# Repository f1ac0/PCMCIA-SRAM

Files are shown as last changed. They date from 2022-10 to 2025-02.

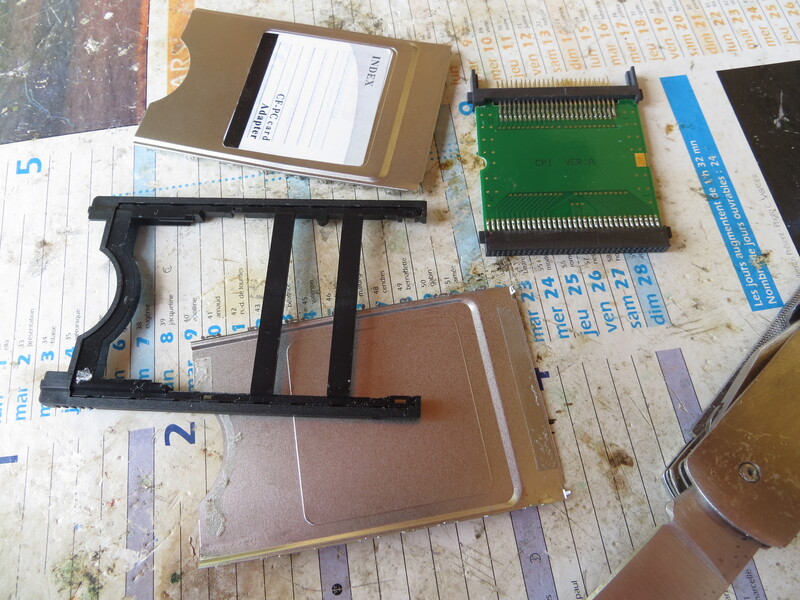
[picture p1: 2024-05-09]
Assembly process/05.The CF-PCMCIA adapter once opened.JPG

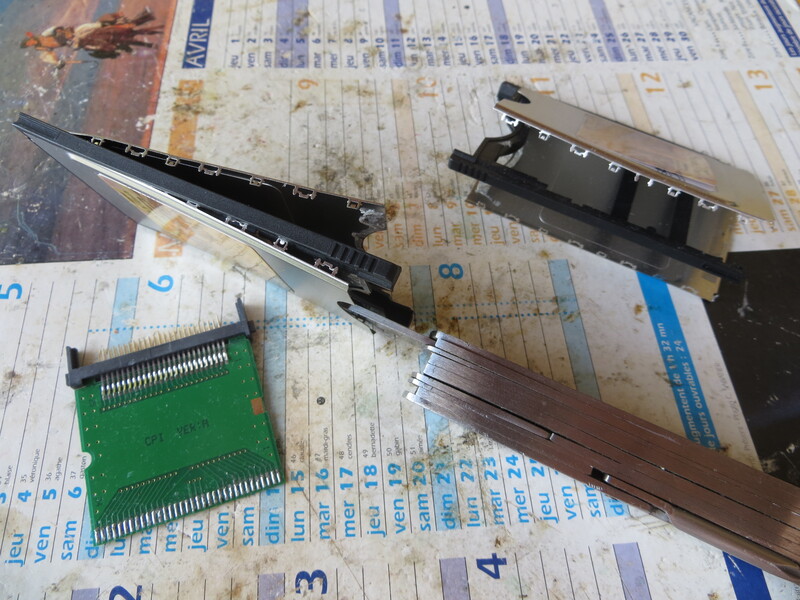
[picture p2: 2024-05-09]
Assembly process/03.Opening the CF-PCMCIA adapter.JPG

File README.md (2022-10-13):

# PCMCIA SRAM
This project is a 4MB or 2MB PCMCIA SRAM for Amiga 600 and 1200, using components available in 2020.

Second hand commercial PCMCIA SRAM cards are rare and expensive. Sakura-IT once created new devices, then published their designs when production was discontinued : https://github.com/Sakura-IT/ppa-pcmcia-sram ; thank you. The idea and CPLD CIS code is inspired from it.

About the project :
- It works in A600 and A1200. It is not tested with any other device. It is 16bit only and does not implement 8bit mode that is required to be compliant to the PCMCIA standard.
- It might work as storage, but is not tested. If you need storage you should just use a CF card and adapter anyway. These days nobody would lose their time fitting a battery in a RAM card.
- It is shorter than a regular PCMCIA card, to be more convenient in our Amiga computers. It is thin enough to fit a standard PCMCIA case. You can fit it in the case and connector of a cheap and available PCMCIA CF adapter. 
- It uses components available in 2020. This is important since there have been several designs but many are already obsolete. Reusing the connector of the aforementioned adapter could be important since they are not so common.
- It uses a 5V SRAM chip to get rid of the level converters. These converters take PCB space, have a cost, and need time to solder. The RAM chip is pricey however, so you might chose to make a 2MB card using just one of it.
- The SRAM chip is fast and the CIS advertise the fastest speed possible. Thanks to this the A600 and A1200 runs faster : they benefit from the added RAM with direct access for the CPU, at least for 16bit applications on the A1200. 

About PCMCIA in Amiga computers, you should already know that its address space is sometimes used by internal accelerators and cannot be used at the same time. If you have such an accelerator, you might not be interested to use this project in the same computer anyway. 

# Disclaimer
This is a hobbyist project, it comes with no warranty and no support. Also remember that the Amiga machines are about 30 years old and may fail because of such hardware expansions.

I publish my work under the CC-BY-NC-SA license. The content of this repository is the result of weeks of work, requiring investment in tools, parts, prototypes, and risky tests on his own equipment. For this reason the author does not want third parties to sell products and keep all the profit, usually without even offering support to their customers. If you see people selling this without the consent of the author, don't buy from them.

If you find it useful and want to reward me : I am always looking for Amiga/Amstrad CPC hardware to repair and hack, please contact me.

# BOM
- 1x or 2x CY62167ELL-45ZXI 5V SRAM (do not use 3.3V CY6167EV !) or 1x CY62177ESL--55ZXI 5V SRAM (not tested by me, tell me if this works for you)
- 1x XC9536XL CPLD
- 1x SPX3819M5-L-3-3 3.3v LDO
- 2x 1uF (or more) 0805 capacitors
- 4x or 5x 100nF 0805 capacitors
- 1x female 68pin PCMCIA connector, or a PCMCIA CF adapter from which you will reuse the connector and case

# Making it
I recommend 0.6mm or 0.8mm PCB since it needs to accommodate the PCMCIA connector and height.

Components are SMD, and TSOP RAM have thin pin pitch. You need to know what you are doing.

Check for shorts at least between 5V, 3.3V, and GND traces before applying power !

The programming port does not need to be soldered since it needs to be programmed just once : you can just hold it in place during the few seconds required for programming.

CPLD code is generated using Xilinx ISE 14.7. There are several methods to program the XC9536XL. I personally use xsvfduino : https://github.com/wschutzer/xsvfduino

NOTE : There are solder pads on the PCB that could be used to implement 8/16bit mode and the "high byte on low pins" feature. Cypress replied that the BYTE mode cannot be used dynamically so it might not work. Amiga computers do not and can not use it anyway.

# Case
To reuse a PCMCIA CF adapter case and connector you first need to disassemble the two metal parts from the plastic body.
- The metal parts are identical and held together by hooks every cm on their long sides. Place the adapter vertically with the long side on the bench. Insert a knife blade between the plastic and the metal on the side of the CF opening, cut the glue, and push down to remove the first hook. The hooks on each side are alternated, so after opening the first one on the left you need to open the next from the right, and so on. Do the same on the other log side. The two remaining hooks are on the short side besides the PCMCIA connector, and the metal part is glued to the PCMCIA connector.
- To desolder the connector from the PCB : lift each pin carefully. Use flux.
- Before soldering the PCMCIA connector to your PCB, bend the pins back to their original place so they will make contact to the PCB. Make sure the board and connector are correctly lined up.
- Cut the indent in the plastic body so you can place the board with soldered connector inside. Cut the plastic body 1 or 2 mm longer than the PCB end.
- Ensure that the PCB is installed the correct way in the plastic body : the guides on the plastic body are keyed. The component side is the top side. THIS IS VERY IMPORTANT.
- Test your card before closing the case. Use AmigaTestKit (https://github.com/keirf/Amiga-Stuff/tree/master/testkit) to test the full 4Mb. Once you are sure the board is OK then you are ready to enclose it.
- With strong scissors, cut both metal parts about 1mm shorter than the plastic body. You may damage your scissors however the result is far better than using a saw.
- Be sure that the metal parts are in good shape and the hooks are aligned. Place the lower one in the plastic body.
- Insulate the top one with tape, at least where the capacitors may touch it. Then place it in the plastic body : the hooks will close it.
- The rear end with sharp metal edges require a protection for your fingers. I personally seal it with hot glue.

# Using it
- Plug it to the PCMCIA port
- Turn amiga on

If you care about your Amiga, this might be a bad idea to plug or unplug the device while live. However if you want to access the CIS info using PrepCard, you need to plug the card after powering the computer.

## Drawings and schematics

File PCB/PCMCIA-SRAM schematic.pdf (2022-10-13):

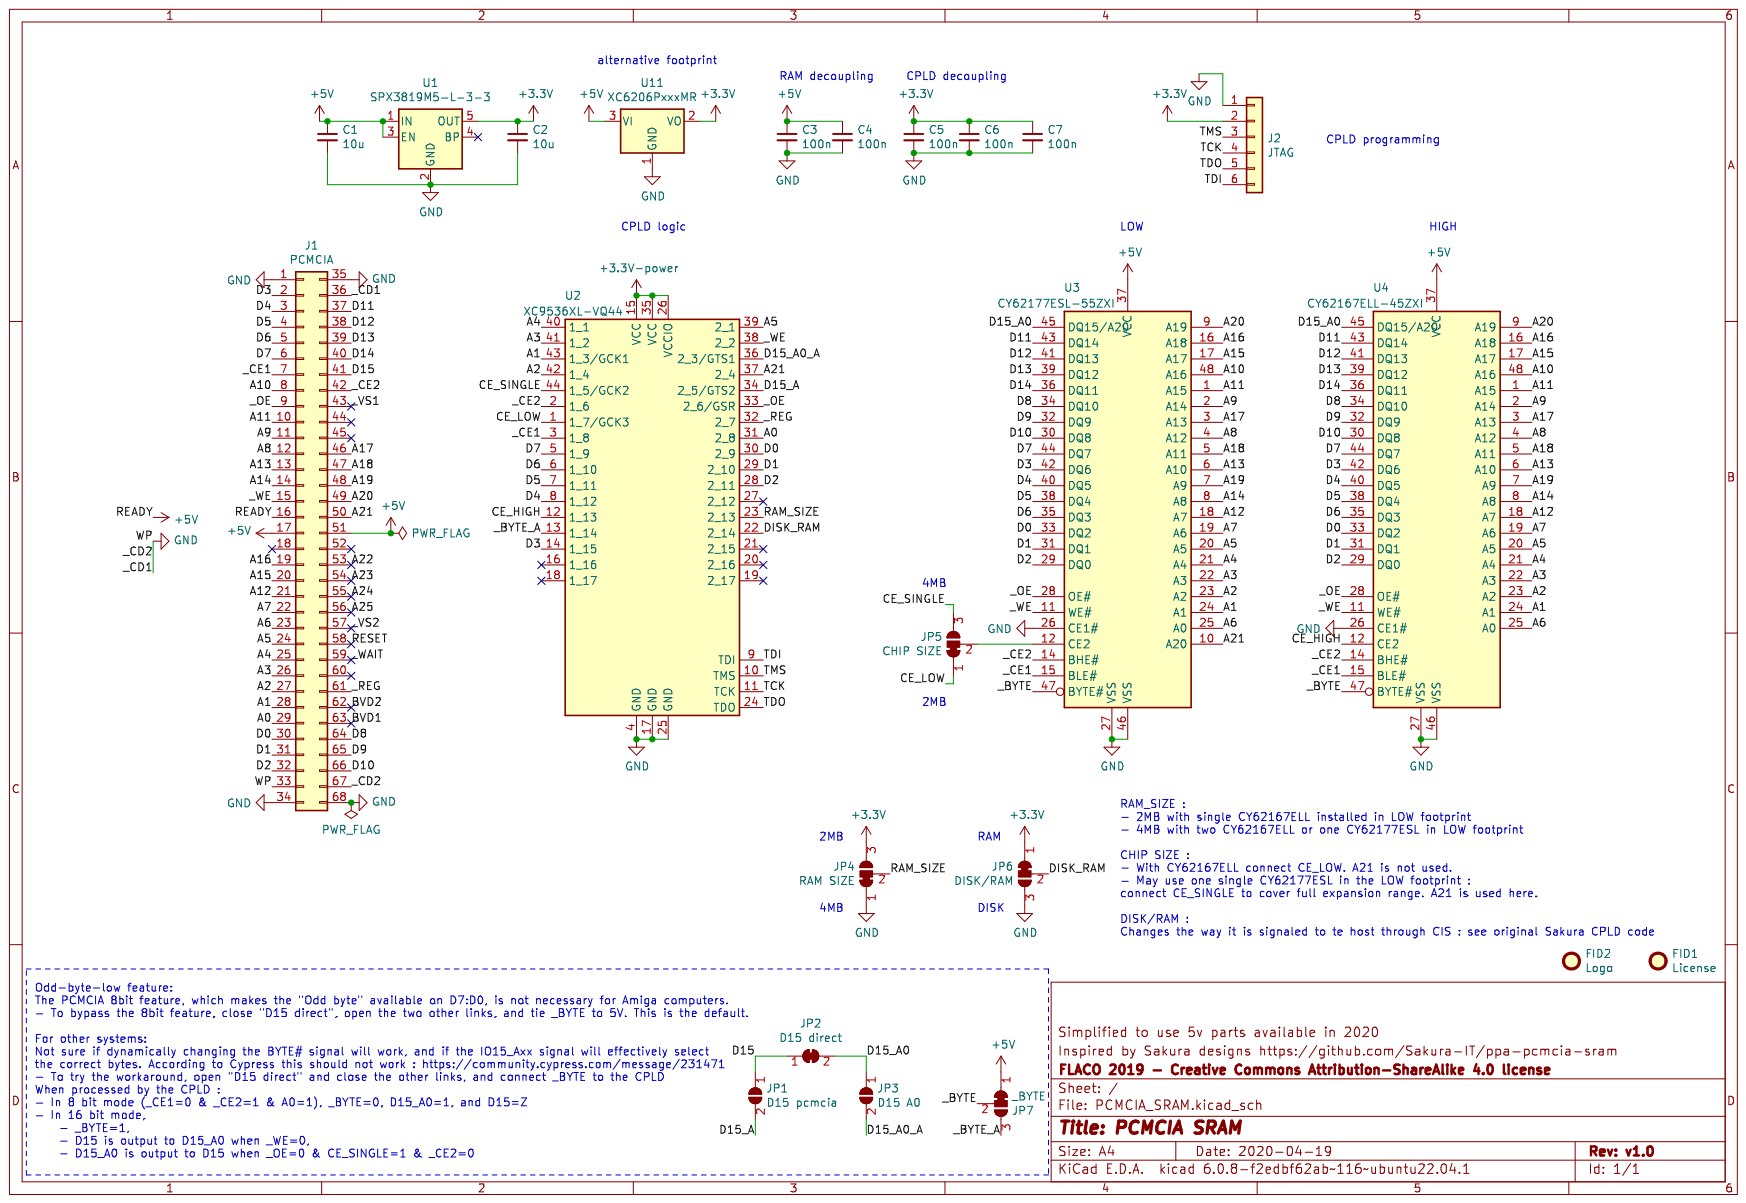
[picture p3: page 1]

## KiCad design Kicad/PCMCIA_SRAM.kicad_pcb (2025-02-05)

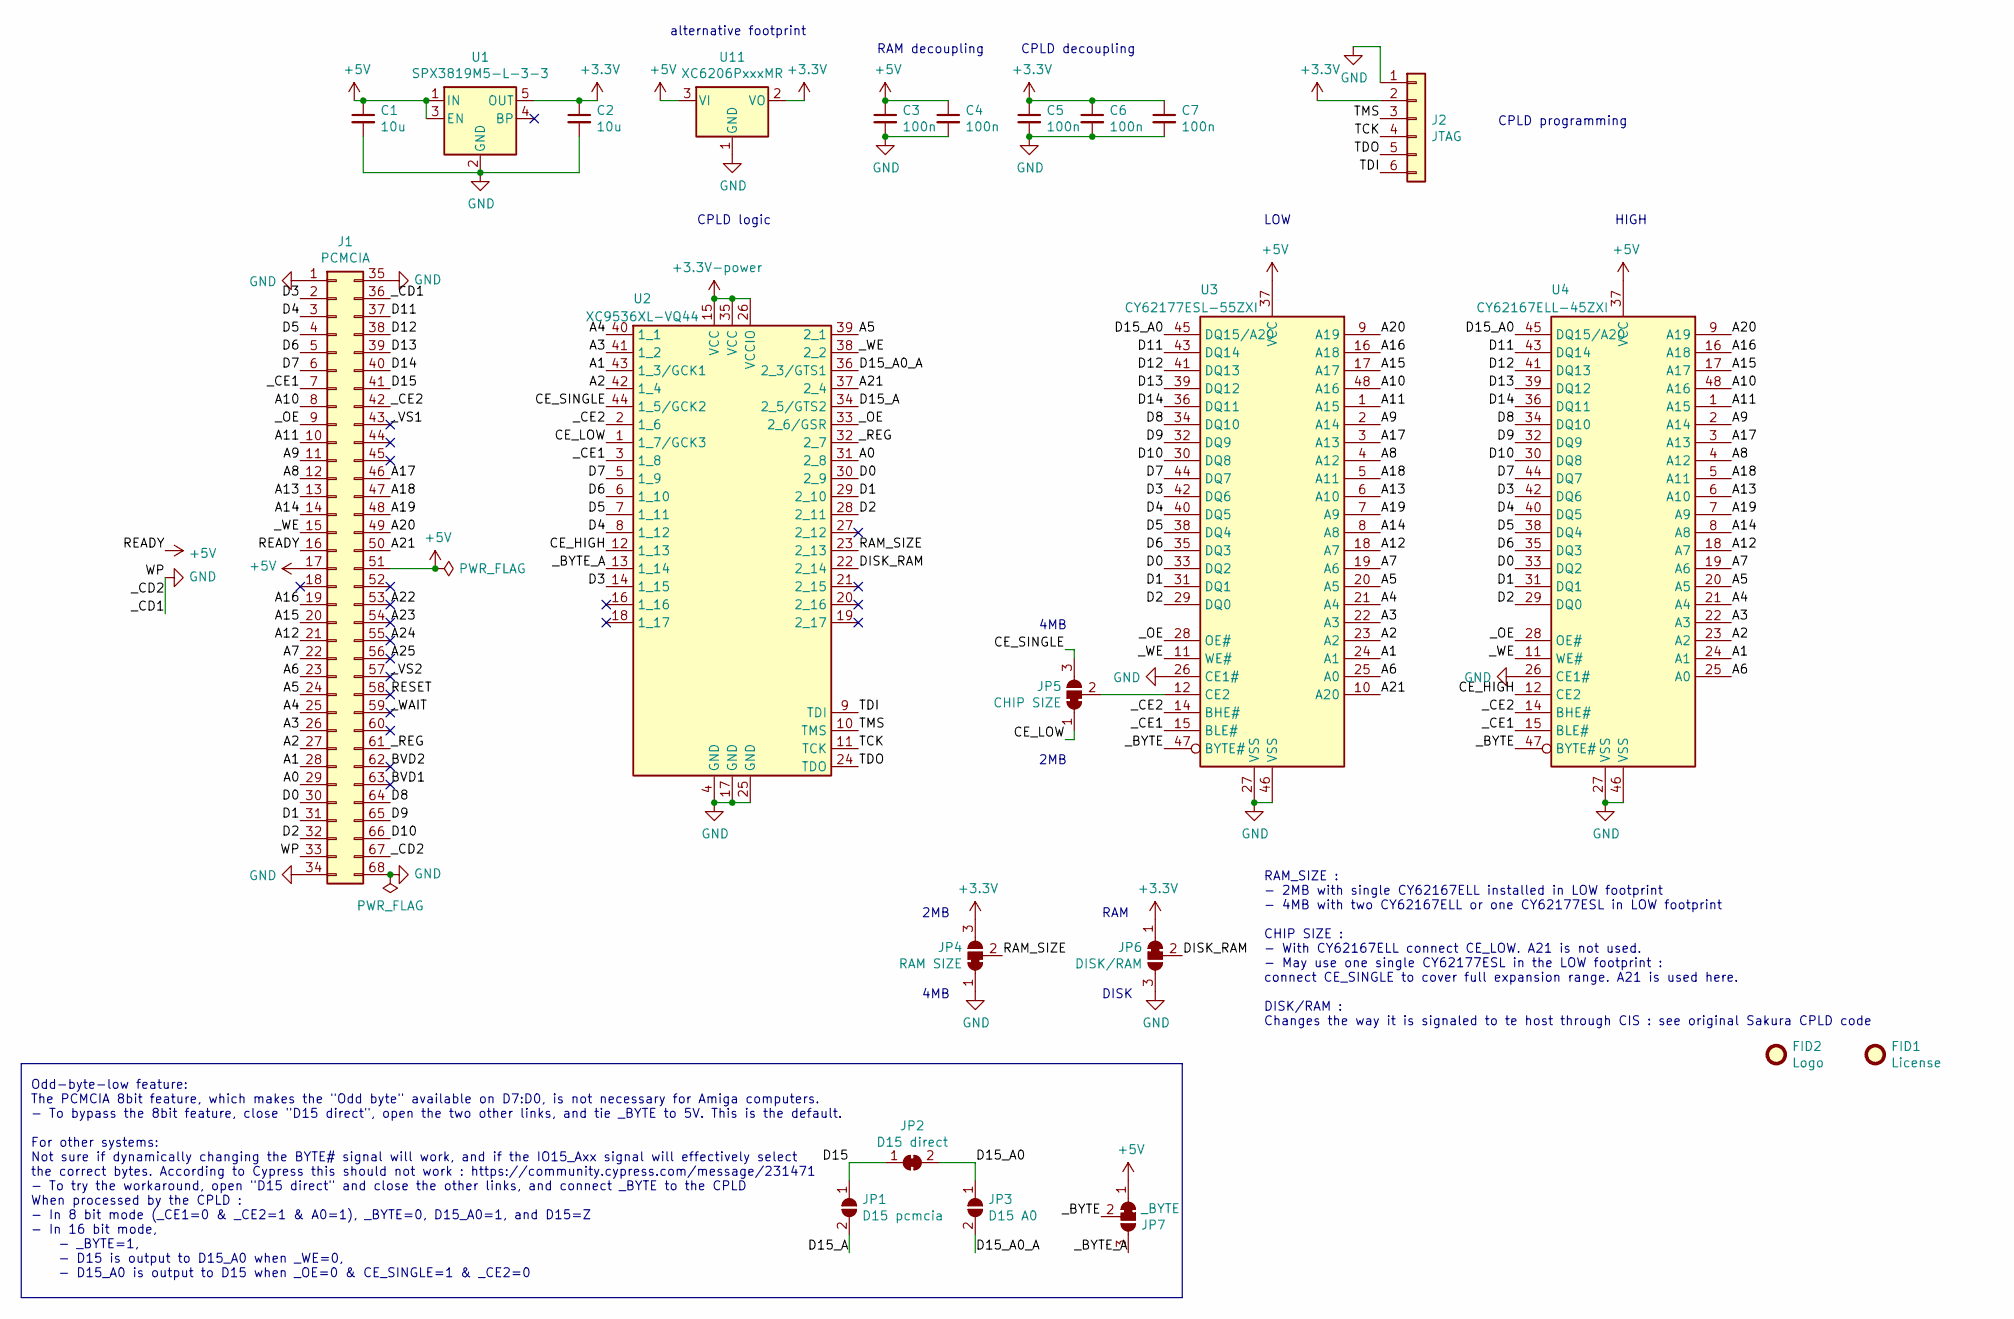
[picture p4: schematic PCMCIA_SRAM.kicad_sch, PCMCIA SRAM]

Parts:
C1, C2: 10u; C_0805_2012Metric
C3, C4, C5, C6, C7: 100n; C_0805_2012Metric
FID1: License; CC_BY_NC_SA_square_silkscreen
FID2: Logo; PIC_Cassepanards_GS
J1: PCMCIA; PCMCIA_female_edge_connector
J2: JTAG; PinHeader_1x06_P2.54mm_Vertical
JP1: D15 pcmcia; SolderJumper-2_P1.3mm_Open_RoundedPad1.0x1.5mm
JP2: D15 direct; SolderJumper-2_P1.3mm_Bridged_RoundedPad1.0x1.5mm
JP3: D15 A0; SolderJumper-2_P1.3mm_Open_RoundedPad1.0x1.5mm
JP4: RAM SIZE; SolderJumper-3_P1.3mm_Bridged12_RoundedPad1.0x1.5mm
JP5: CHIP SIZE; SolderJumper-3_P1.3mm_Bridged12_RoundedPad1.0x1.5mm
JP6: DISK/RAM; SolderJumper-3_P1.3mm_Bridged12_RoundedPad1.0x1.5mm
JP7: _BYTE; SolderJumper-3_P1.3mm_Bridged12_RoundedPad1.0x1.5mm
U1: SPX3819M5-L-3-3; SOT-23-5
U2: XC9536XL-VQ44; LQFP-44_10x10mm_P0.8mm
U3: CY62177ESL-55ZXI; TSOP-I-48_18.4x12mm_P0.5mm
U4: CY62167ELL-45ZXI; TSOP-I-48_18.4x12mm_P0.5mm
U11: XC6206PxxxMR; SOT-23

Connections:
+5V: C1.1, C3.1, C4.1, J1.16, J1.17, J1.51, JP7.1 (A), U1.1 (IN), U1.3 (EN), U3.37 (VCC), U4.37 (VCC), U11.3 (VI)
/A0: J1.29, U2.31 (2_8)
/A1: J1.28, U2.43 (1_3/GCK1), U3.24 (A1), U4.24 (A1)
/A2: J1.27, U2.42 (1_4), U3.23 (A2), U4.23 (A2)
/A3: J1.26, U2.41 (1_2), U3.22 (A3), U4.22 (A3)
/A4: J1.25, U2.40 (1_1), U3.21 (A4), U4.21 (A4)
/A5: J1.24, U2.39 (2_1), U3.20 (A5), U4.20 (A5)
/A6: J1.23, U3.25 (A0), U4.25 (A0)
/A7: J1.22, U3.19 (A6), U4.19 (A6)
/A8: J1.12, U3.4 (A12), U4.4 (A12)
/A9: J1.11, U3.2 (A14), U4.2 (A14)
/A10: J1.8, U3.48 (A16), U4.48 (A16)
/A11: J1.10, U3.1 (A15), U4.1 (A15)
/A12: J1.21, U3.18 (A7), U4.18 (A7)
/A13: J1.13, U3.6 (A10), U4.6 (A10)
/A14: J1.14, U3.8 (A8), U4.8 (A8)
/A15: J1.20, U3.17 (A17), U4.17 (A17)
/A16: J1.19, U3.16 (A18), U4.16 (A18)
/A17: J1.46, U3.3 (A13), U4.3 (A13)
/A18: J1.47, U3.5 (A11), U4.5 (A11)
/A19: J1.48, U3.7 (A9), U4.7 (A9)
/A20: J1.49, U3.9 (A19), U4.9 (A19)
/A21: J1.50, U2.37 (2_4), U3.10 (A20)
/A22: J1.53
/A23: J1.54
/A24: J1.55
/A25: J1.56
/BVD1: J1.63
/BVD2: J1.62
/CE_HIGH: U2.12 (1_13), U4.12 (CE2)
/CE_LOW: JP5.1 (A), U2.1 (1_7/GCK3)
/CE_SINGLE: JP5.3 (B), U2.44 (1_5/GCK2)
/D0: J1.30, U2.30 (2_9), U3.33 (DQ2), U4.33 (DQ2)
/D1: J1.31, U2.29 (2_10), U3.31 (DQ1), U4.31 (DQ1)
/D2: J1.32, U2.28 (2_11), U3.29 (DQ0), U4.29 (DQ0)
/D3: J1.2, U2.14 (1_15), U3.42 (DQ6), U4.42 (DQ6)
/D4: J1.3, U2.8 (1_12), U3.40 (DQ5), U4.40 (DQ5)
/D5: J1.4, U2.7 (1_11), U3.38 (DQ4), U4.38 (DQ4)
/D6: J1.5, U2.6 (1_10), U3.35 (DQ3), U4.35 (DQ3)
/D7: J1.6, U2.5 (1_9), U3.44 (DQ7), U4.44 (DQ7)
/D8: J1.64, U3.34 (DQ10), U4.34 (DQ10)
/D9: J1.65, U3.32 (DQ9), U4.32 (DQ9)
/D10: J1.66, U3.30 (DQ8), U4.30 (DQ8)
/D11: J1.37, U3.43 (DQ14), U4.43 (DQ14)
/D12: J1.38, U3.41 (DQ13), U4.41 (DQ13)
/D13: J1.39, U3.39 (DQ12), U4.39 (DQ12)
/D14: J1.40, U3.36 (DQ11), U4.36 (DQ11)
/D15: J1.41, JP1.1 (A), JP2.1 (A)
/D15_A: JP1.2 (B), U2.34 (2_5/GTS2)
/D15_A0: JP2.2 (B), JP3.1 (A), U3.45 (DQ15/A20), U4.45 (DQ15/A20)
/D15_A0_A: JP3.2 (B), U2.36 (2_3/GTS1)
/DISK_RAM: JP6.2 (C), U2.22 (2_14)
/RAM_SIZE: JP4.2 (C), U2.23 (2_13)
/RESET: J1.58
/TCK: J2.4, U2.11 (TCK)
/TDI: J2.6, U2.9 (TDI)
/TDO: J2.5, U2.24 (TDO)
/TMS: J2.3, U2.10 (TMS)
/_BYTE: JP7.2 (C), U3.47 (BYTE#), U4.47 (BYTE#)
/_BYTE_A: JP7.3 (B), U2.13 (1_14)
/_CE1: J1.7, U2.3 (1_8), U3.15 (BLE#), U4.15 (BLE#)
/_CE2: J1.42, U2.2 (1_6), U3.14 (BHE#), U4.14 (BHE#)
/_OE: J1.9, U2.33 (2_6/GSR), U3.28 (OE#), U4.28 (OE#)
/_REG: J1.61, U2.32 (2_7)
/_VS1: J1.43
/_VS2: J1.57
/_WAIT: J1.59
/_WE: J1.15, U2.38 (2_2), U3.11 (WE#), U4.11 (WE#)
GND: C1.2, C2.2, C3.2, C4.2, C5.2, C6.2, C7.2, J1.1, J1.33, J1.34, J1.35, J1.36, J1.67, J1.68, J2.1, JP4.1 (A), JP6.3 (B), U1.2 (GND), U2.4 (GND), U2.17 (GND), U2.25 (GND), U3.26 (CE1#), U3.27 (VSS), U3.46 (VSS), U4.26 (CE1#), U4.27 (VSS), U4.46 (VSS), U11.1 (GND)
unnamed: JP5.2 (C), U3.12 (CE2)

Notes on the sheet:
2MB
4MB
DISK
RAM
HIGH
alternative footprint
CPLD programming
CPLD decoupling
LOW
RAM decoupling
Odd-byte-low feature: The PCMCIA 8bit feature, which makes the "Odd byte" available on D7:D0, is not necessary for Amiga computers. - To bypass the 8bit feature, close "D15 direct", open the two other links, and tie _BYTE to 5V. This is the default. For other systems: Not sure if dynamically changi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
CPLD logic
RAM_SIZE : - 2MB with single CY62167ELL installed in LOW footprint - 4MB with two CY62167ELL or one CY62177ESL in LOW footprint CHIP SIZE : - With CY62167ELL connect CE_LOW. A21 is not used. - May use one single CY62177ESL in the LOW footprint : connect CE_SINGLE to cover full expansion range. A21 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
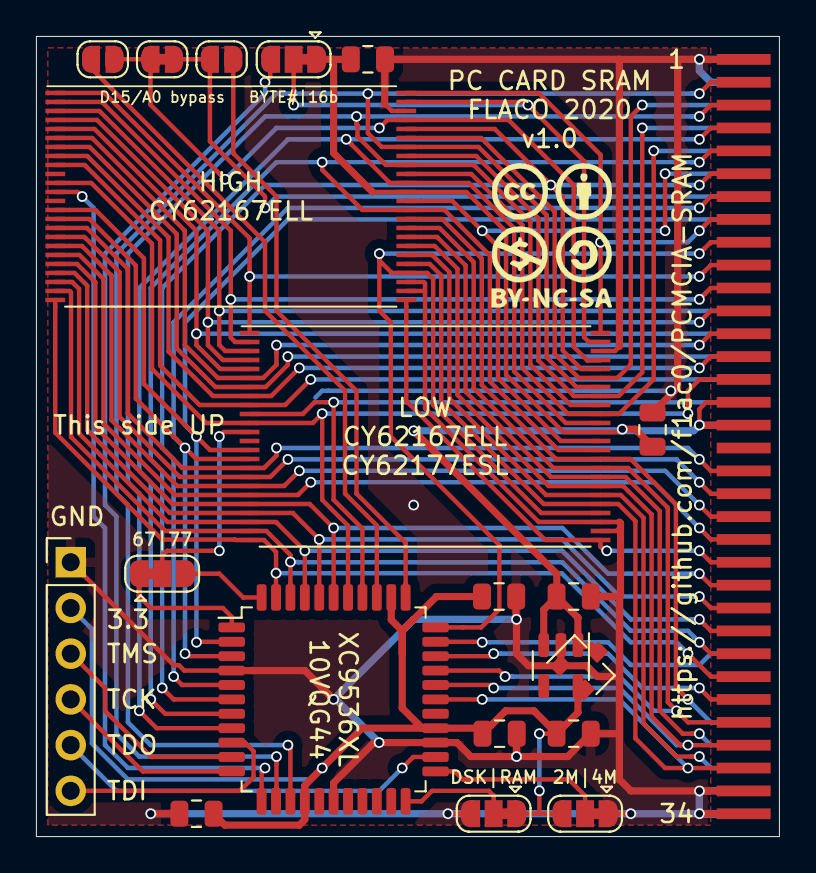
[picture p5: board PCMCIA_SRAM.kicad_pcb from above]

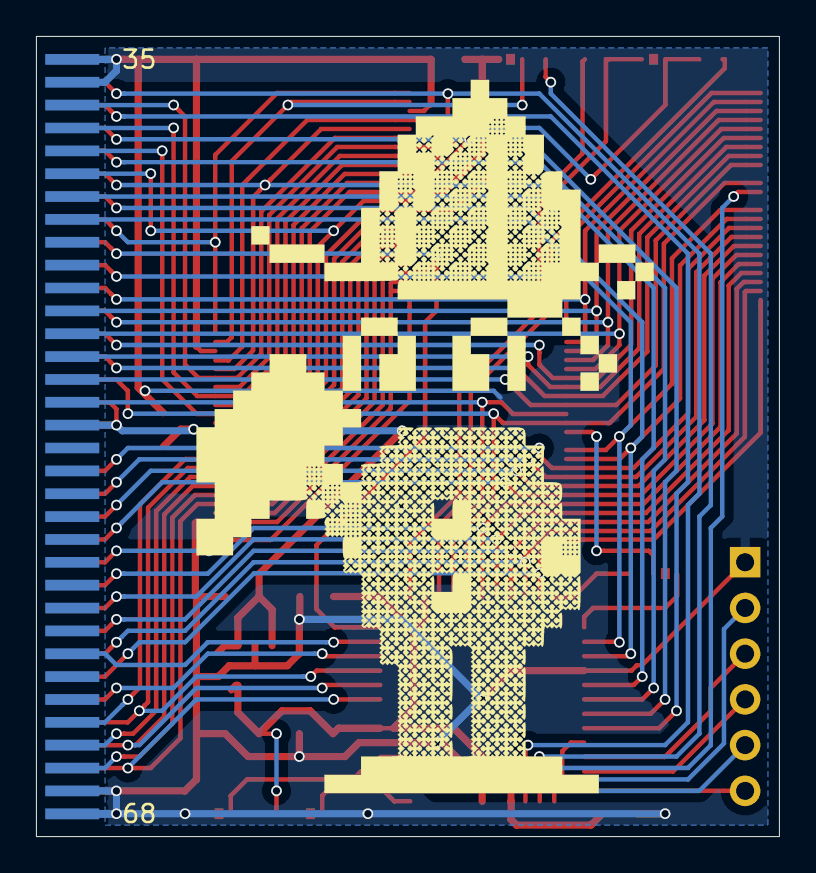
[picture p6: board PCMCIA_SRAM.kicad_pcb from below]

Board: 2 copper layers, 41.3 x 44.5 mm, 23 parts (2 on the bottom side), 61 nets.

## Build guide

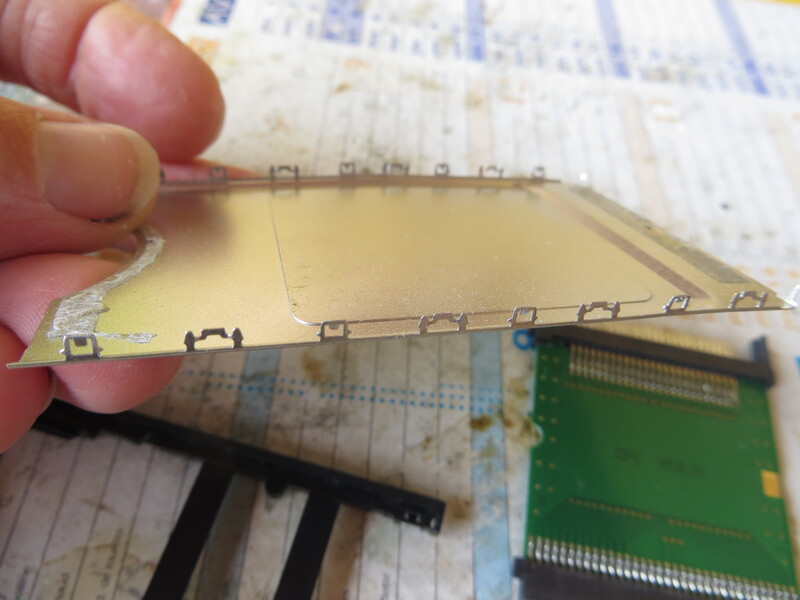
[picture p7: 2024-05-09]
Assembly process/04.The metallic clipses you need to open.JPG

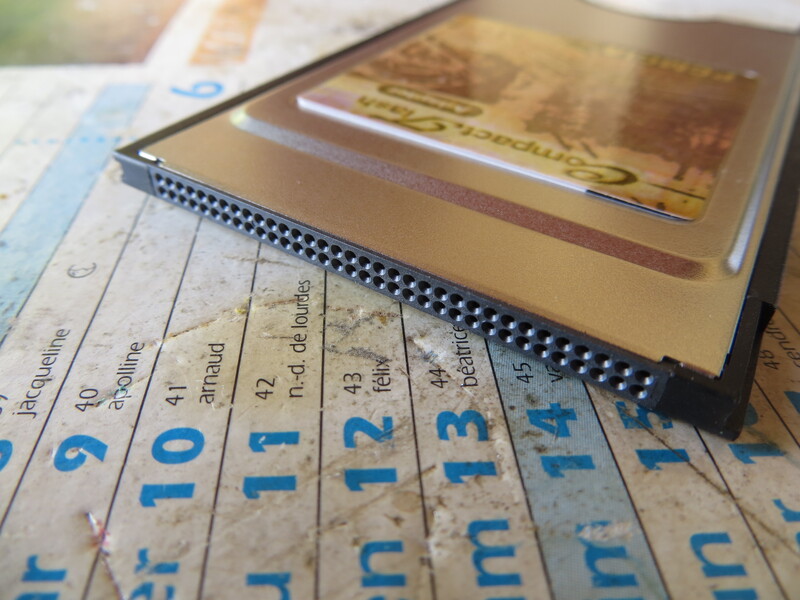
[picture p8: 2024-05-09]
Assembly process/02.The CF-PCMCIA connector.JPG

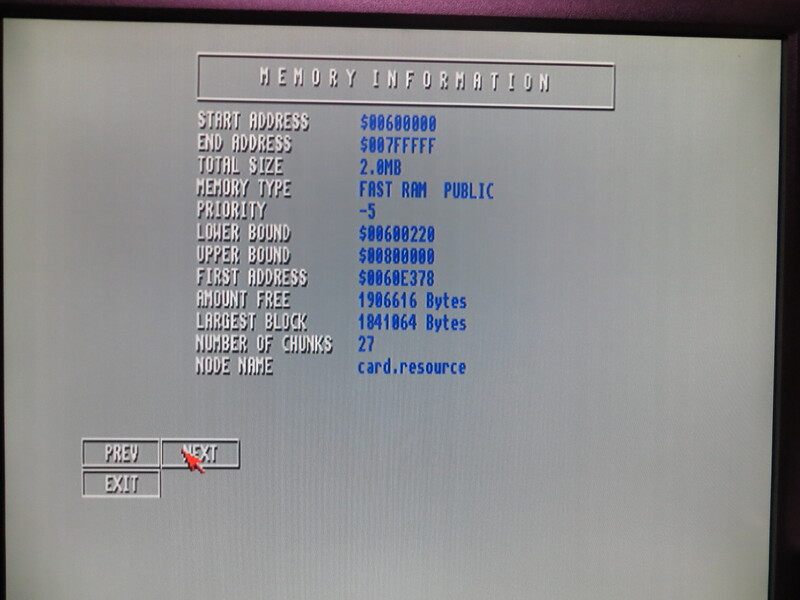
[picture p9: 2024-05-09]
Assembly process/11.The board is detected by SysInfo.JPG

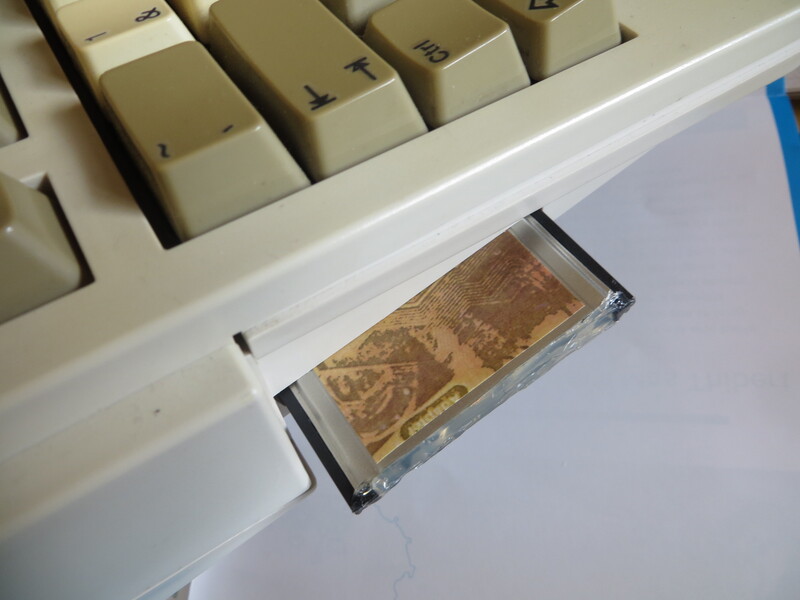
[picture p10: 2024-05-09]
Assembly process/19.Ready to go.JPG

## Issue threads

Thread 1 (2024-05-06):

CY62167ELL-45ZXI

hardgb, 2024-05-06:
First I apologize for my English, it is terrible.
I also want to thank you for the project. I am very interested in assembling at least 2 units of this PCMCIA SRAM for my 2 A600.
I have a doubt.
#The "CY62167ELL-45ZXI" that I'm finding is 3.6V, I can't find the 5V one. Can I use it?

Do you have a video showing how this card works?
Do you have more photos of the card?

My email: hard_gb@hotmail.com

f1ac0, 2024-05-09:
Hello hargb,
As stated in the readme, it is important to use 5V parts, since there is no voltage conversion on the board that would make it far more complicated and larger.
There are other Cypress SRAM chips that run at lower voltages. The CY62167ELL-45ZXI also internally runs at at a lower voltage but has an internal regulator and 5V tolerant pins, maybe this is the reason why yous vendor states it is 3.6V in his description ?

I just added the photos I have inside the repo to help for the assembly process.

I suggest you remove your email from your comment, spammers will target you.

hardgb, 2024-05-09:
Many thanks for the reply.
I tried to do it

f1ac0, 2024-05-09:
Here are some additional advice for the assembly :
- The board has two overlapping footprints for two possible regulators. I see that I forgot to mention in the readme that the SOT23 one I used is a XC6206P332MR. Look at the ibom file how to install it
- On picture n°9 the board has only one CY62167ELL-45ZXI RAM chip : this was during development, that would need a different CPLD logic, so you need to install both.
- If you do not have a Xilinx programmer, look at https://github.com/f1ac0/xsvfduino. You may also use a raspberry Pi, see https://github.com/f1ac0/PistormX/tree/main/Alpha#programming-the-cpld-from-the-pi
- Look at the photo how the metallic clipses are made, to remove them it is easier to start on the CF side, insert the knife in order to always push out the base of the small clips that has a small "tongue" that grips to the longer clips from the other lid.
- When desoldering the PCMCIA connector, be careful not to bend too much the pins since they are fragile. You need to use a lot of flux and a desoldering braid in order to remove as much solder as possible to help in the process
- Always check for shorts, at least on the power rails, before powering it to program the CPLD and connecting it to your system
- Test it before you put it inside the enclosure
- Beware of the sharp edges of the metallic covers
Good luck !

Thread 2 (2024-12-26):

Npn-attribute memory option for old scope

Kobbe1, 2024-12-26:
Hi @f1ac0 ,
I was thinking to maybe build one of these PCBs to resurrect one of my LeCroy scopes - which will require some changes to the source code it seems, some details of what is required are here:
https://github.com/Sakura-IT/ppa-pcmcia-sram/issues/1

Also here just FYI regarding the background:
https://groups.io/g/LeCroyOwnersGroup/topic/lt342_boot_issue/77501370

I should be able to build the PCB, I have access to a microscope etc. if needed, and I think I can figure the FPGA programming - but how do I adjust the source code? Primarily regarding the above "non-attribute" adjustments as well as adjusting for only the one used SRAM chip so I get a 2Mb card ...
Or is zhis using the original source code from https://github.com/Sakura-IT/ppa-pcmcia-sram/tree/master/cpld/src ?

Thanks,

-T

f1ac0, 2024-12-27:
Hi Kobbe1,
I just added a new file that does not respond to ROM attributes, the same as what you pointed inside the Sakura-IT repo.
Without the ROM attribute, there is nothing to do in the firmware to have a 2MB card: just install the LOW ram chip and leave the HIGH one unpopulated.
Please report if you have the opportunity to try it.

Kobbe1, 2024-12-27:
I am about to order the PCB and components from Ali, and realized that of course the design has no battery, so obviously it will lose whatever I write to it when I pull this from the PCMCIA slot.

Obviously that is not an issue when being used in an Amiga (I had an A600 and A1200 once back in the day :) btw ) - but here for the scope I guess I will need to attach a battery to externally power it after programming.

The background is that my LeCroy scope LT344 has lost its firmware, so I need to write the firmware to a "linear non-attribute SRAM" card and then boot the scope from there, then flash it back to the original IC.

It wont be an issue really, I can put some USB connector on the back and power it from an power bank for example, just wanted to hear your thoughts ...

f1ac0, 2024-12-28:
The PCB is not designed to use a battery to power the RAM chips : no terminals for it, no protection to prevent sending power from the battery to the host system when it is off or feeding the 5V from the host inside the battery. In addition the RAM chips use an active high CE pin that could prevent selecting the chip and writing to it when the CPLD is not powered, but the PCB is not designed to power only the RAM chips and shut down the LDO and the CPLD.

You may lift the PCMCIA pins 16,17 and 51 and install a 3.3V-5V battery terminals around C1, C3 or C4 and see if it is enough for your application.
If not, then you would have to solder all the PCMCIA pins then cut the 5V trace just in front of pin 37 of U3 the LOW ram chip (to isolate it from the LDO/CPLD and host system) then connect the battery around C4 to power the RAM chip.

See the IBOM file to locate the chips.

A you say this was designed to be used with Amiga computers and it does not implement switching between 8bits and 16bits modes that are part of the PCMCIA spec. I do not know if there are systems using this feature.

Kobbe1, 2025-08-15:
Hi,
I found some time and energy to finally try to program the device.
Unfortunately I did not get it to respond.

I am using a serial to USB device.

I start the upload through python, and get the "ready to send". Then press reset on the bluepill.

Of course it might be the soldering, but I have no way to really debug this. The PCB looks a bit nasty but that is mostly dust as it was sitting here for months on my desk ...

I did try it earlier with the USBserial of the bluepill, there was more output but also no actual programming. Will try again ...

`
C:\Users\Kobbe>python "D:\Dev\send_xsvf" -p COM8 "D:\Dev\PCMCIA_RAM_no_attribute_ROM.xsvf"
Ready to send file of size 39453 bytes.

<pressed reset here>

DEBUG:  A
Device is ready.
DEBUG: SENT:  07201200120104000000000208fe0800000020010fffffff0900000000f96020
DEBUG:  G    sizeof( SXsvfInfo ) = 1848 bytes

Device: sizeof( SXsvfInfo ) = 1848 bytes
DEBUG:  G   TMS Reset Sequence -> Test-Logic-Reset
Device: TMS Reset Sequence -> Test-Logic-Reset
DEBUG:  G   TAP State = RESET
Device: TAP State = RESET
`

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

Kobbe1, 2025-08-15:
bit more progress by flashing the right bootloader to use the USBSerial. Probably this comes down to hw problem now, might need to resolder or replace FPGA ...

```
C:\Users\Kobbe>python "D:\Dev\send_xsvf" -p COM9 "D:\Dev\PCMCIA_RAM_no_attribute_ROM.xsvf"
Ready to send file of size 39453 bytes.
DEBUG:  A
Device is ready.
DEBUG: SENT:  07201200120104000000000208fe0800000020010fffffff0900000000f96020
DEBUG:  G  XREPEAT

Device: XREPEAT
DEBUG:  G   XREPEAT = 32
Device: XREPEAT = 32
DEBUG:  G  XSTATE
Device: XSTATE
DEBUG:  G   TMS Reset Sequence -> Test-Logic-Reset
Device: TMS Reset Sequence -> Test-Logic-Reset
DEBUG:  G   TAP State = RESET
Device: TAP State = RESET
DEBUG:  G  XSTATE
Device: XSTATE
DEBUG:  G   TAP State = RUNTEST/IDLE
Device: TAP State = RUNTEST/IDLE
DEBUG:  G  XRUNTEST
Device: XRUNTEST
DEBUG:  G   XRUNTEST = 0
Device: XRUNTEST = 0
DEBUG:  G  XSIR
Device: XSIR
DEBUG:  G   XSIR length = 8
Device: XSIR length = 8
DEBUG:  G   Shift Length = 8
Device: Shift Length = 8
DEBUG:  G    TDI          = 0xfe
Device: TDI          = 0xfe
DEBUG:  G    TDO Expected =
Device: TDO Expected =
DEBUG:  ff
Unrecognized line: ff
DEBUG:  G  XSDRTDO
Device: XSDRTDO
DEBUG:  A
DEBUG: SENT:  930208ff0208e8080000000601000905000208ed0400030d4008000000120100
DEBUG:  G   Shift Length = 32

Device: Shift Length = 32
DEBUG:  G    TDI          = 0x00000000
Device: TDI          = 0x00000000
DEBUG:  G    TDO Expected = 0xf9602093
Device: TDO Expected = 0xf9602093
DEBUG:  G   TAP State = DRSELECT
Device: TAP State = DRSELECT
DEBUG:  G   TAP State = DRCAPTURE
Device: TAP State = DRCAPTURE
DEBUG:  G   TAP State = DRSHIFT
Device: TAP State = DRSHIFT
DEBUG:  G   TAP State = DREXIT1
Device: TAP State = DREXIT1
DEBUG:  G   TAP State = DRUPDATE
Device: TAP State = DRUPDATE
DEBUG:  G   TAP State = RUNTEST/IDLE
Device: TAP State = RUNTEST/IDLE
DEBUG:  G   TAP State = DRSELECT
Device: TAP State = DRSELECT
DEBUG:  G   TAP State = DRCAPTURE
Device: TAP State = DRCAPTURE
DEBUG:  G   TAP State = DRSHIFT
Device: TAP State = DRSHIFT
DEBUG:  G   TAP State = DREXIT1
Device: TAP State = DREXIT1
DEBUG:  G  G   TAP State = DREXIT1
Device: G   TAP State = DREXIT1
DEBUG:  G   TAP State = DRUPDATE
Device: TAP State = DRUPDATE
DEBUG:  G   TAP State = RUNTEST/IDLE
Device: TAP State = RUNTEST/IDLE
DEBUG:  G   TAP State = DRSELECT
Device: TAP State = DRSELECT
DEBUG:  G   TAP State = DRCAPTURE
Device: TAP State = DRCAPTURE
DEBUG:  G   TAP State = DRSHIFT
Device: TAP State = DRSHIFT
DEBUG:  G   TAP State = DREXIT1
Device: TAP State = DREXIT1
DEBUG:  G   TAP State = DRUPDATE
Device: TAP State = DRUPDATE
DEBUG:  G   TAP State = RUNTEST/IDLE
Device: TAP State = RUNTEST/IDLE
DEBUG:  G   TAP State = DRSELECT
Device: TAP State = DRSELECT
DEBUG:  G   TAP State = DRCAPTURE
Device: TAP State = DRCAPTURE
DEBUG:  G   TAP State = DRSHIFT
Device: TAP State = DRSHIFT
DEBUG:  G   TAP State = DREXIT1
Device: TAP State = DREXIT1
DEBUG:  G   TAP State = DRUPDATE
Device: TAP State = DRUPDATE
DEBUG:  G   TAP State = RUNTEST/IDLE
Device: TAP State = RUNTEST/IDLE
DEBUG:  G   TAP State = DRSELECT
Device: TAP State = DRSELECT
DEBUG:  G   TAP State = DRCAPTURE
Device: TAP State = DRCAPTURE
DEBUG:  G   TAP State = DRSHIFT
Device: TAP State = DRSHIFT
DEBUG:  G   TAP State = DREXIT1
Device: TAP State = DREXIT1
DEBUG:  G   TAP State = DRUPDATE
Device: TAP State = DRUPDATE
DEBUG:  G   TAP State = RUNTEST/IDLE
Device: TAP State = RUNTEST/IDLE
DEBUG:  G   TAP State = DRSELECT
Device: TAP State = DRSELECT
DEBUG:  G   TAP State = DRCAPTURE
Device: TAP State = DRCAPTURE
DEBUG:  G   TAP State = DRSHIFT
Device: TAP State = DRSHIFT
DEBUG:  G   TAP State = DREXIT1
Device: TAP State = DREXIT1
DEBUG:  G   TAP State = DRUPDATE
Device: TAP State = DRUPDATE
DEBUG:  G   TAP State = RUNTEST/IDLE
Device: TAP State = RUNTEST/IDLE
DEBUG:  G   TAP State = DRSELECT
Device: TAP State = DRSELECT
DEBUG:  G   TAP State = DRCAPTURE
Device: TAP State = DRCAPTURE
DEBUG:  G   TAP State = DRSHIFT
Device: TAP State = DRSHIFT
DEBUG:  G   TAP State = DREXIT1
Device: TAP State = DREXIT1
DEBUG:  G   TAP State = DRUPDATE
Device: TAP State = DRUPDATE
DEBUG:  G   TAP State = RUNTEST/IDLE
Device: TAP State = RUNTEST/IDLE
DEBUG:  G   TAP State = DRSELECT
Device: TAP State = DRSELECT
DEBUG:  G   TAP State = DRCAPTURE
Device: TAP State = DRCAPTURE
DEBUG:  G   TAP State = DRSHIFT
Device: TAP State = DRSHIFT
DEBUG:  G   TAP State = DREXIT1
Device: TAP State = DREXIT1
DEBUG:  G   TAP State = DRUPDATE
Device: TAP State = DRUPDATE
DEBUG:  G   TAP State = RUNTEST/IDLE
Device: TAP State = RUNTEST/IDLE
DEBUG:  G   TAP State = DRSELECT
Device: TAP State = DRSELECT
DEBUG:  G   TAP State = DRCAPTURE
Device: TAP State = DRCAPTURE
DEBUG:  G   TAP State = DRSHIFT
Device: TAP State = DRSHIFT
DEBUG:  G   TAP State = DREXIT1
Device: TAP State = DREXIT1
DEBUG:  G   TAP State = DRUPDATE
Device: TAP State = DRUPDATE
DEBUG:  G   TAP State = RUNTEST/IDLE
Device: TAP State = RUNTEST/IDLE
DEBUG:  G   TAP State = DRSELECT
Device: TAP State = DRSELECT
DEBUG:  G   TAP State = DRCAPTURE
Device: TAP State = DRCAPTURE
DEBUG:  G   TAP State = DRSHIFT
Device: TAP State = DRSHIFT
DEBUG:  G   TAP State = DREXIT1
Device: TAP State = DREXIT1
DEBUG:  G   TAP State = DRUPDATE
Device: TAP State = DRUPDATE
DEBUG:  G   TAP State = RUNTEST/IDLE
Device: TAP State = RUNTEST/IDLE
DEBUG:  G   TAP State = DRSELECT
Device: TAP State = DRSELECT
DEBUG:  G   TAP State = DRCAPTURE
Device: TAP State = DRCAPTURE
DEBUG:  G   TAP State = DRSHIFT
Device: TAP State = DRSHIFT
DEBUG:  G   TAP State = DREXIT1
Device: TAP State = DREXIT1
DEBUG:  G   TAP State = DRUPDATE
Device: TAP State = DRUPDATE
DEBUG:  G   TAP State = RUNTEST/IDLE
Device: TAP State = RUNTEST/IDLE
DEBUG:  G   TAP State = DRSELECT
Device: TAP State = DRSELECT
DEBUG:  G   TAP State = DRCAPTURE
Device: TAP State = DRCAPTURE
DEBUG:  G   TAP State = DRSHIFT
Device: TAP State = DRSHIFT
DEBUG:  G   TAP State = DREXIT1
Device: TAP State = DREXIT1
DEBUG:  G   TAP State = DRUPDATE
Device: TAP State = DRUPDATE
DEBUG:  G   TAP State = RUNTEST/IDLE
Device: TAP State = RUNTEST/IDLE
DEBUG:  G   TAP State = DRSELECT
Device: TAP State = DRSELECT
DEBUG:  G   TAP State = DRCAPTURE
Device: TAP State = DRCAPTURE
DEBUG:  G   TAP State = DRSHIFT
Device: TAP State = DRSHIFT
DEBUG:  G   TAP State = DREXIT1
Device: TAP State = DREXIT1
DEBUG:  G   TAP State = DRUPDATE
Device: TAP State = DRUPDATE
DEBUG:  G   TAP State = RUNTEST/IDLE
Device: TAP State = RUNTEST/IDLE
DEBUG:  G   TAP State = DRSELECT
Device: TAP State = DRSELECT
DEBUG:  G   TAP State = DRCAPTURE
Device: TAP State = DRCAPTURE
DEBUG:  G   TAP State = DRSHIFT
Device: TAP State = DRSHIFT
DEBUG:  G   TAP State = DREXIT1
Device: TAP State = DREXIT1
DEBUG:  G   TAP State = DRUPDATE
Device: TAP State = DRUPDATE
DEBUG:  G   TAP State = RUNTEST/IDLE
Device: TAP State = RUNTEST/IDLE
DEBUG:  G   TAP State = DRSELECT
Device: TAP State = DRSELECT
DEBUG:  G   TAP State = DRCAPTURE
Device: TAP State = DRCAPTURE
DEBUG:  G   TAP State = DRSHIFT
Device: TAP State = DRSHIFT
DEBUG:  G   TAP State = DREXIT1
Device: TAP State = DREXIT1
DEBUG:  G   TAP State = DRUPDATE
Device: TAP State = DRUPDATE
DEBUG:  G   TAP State = RUNTEST/IDLE
Device: TAP State = RUNTEST/IDLE
DEBUG:  G   TAP State = DRSELECT
Device: TAP State = DRSELECT
DEBUG:  G   TAP State = DRCAPTURE
Device: TAP State = DRCAPTURE
DEBUG:  G   TAP State = DRSHIFT
Device: TAP State = DRSHIFT
DEBUG:  G   TAP State = DREXIT1
Device: TAP State = DREXIT1
DEBUG:  G   TAP State = DRUPDATE
Device: TAP State = DRUPDATE
DEBUG:  G   TAP State = RUNTEST/IDLE
Device: TAP State = RUNTEST/IDLE
DEBUG:  G   TAP State = DRSELECT
Device: TAP State = DRSELECT
DEBUG:  G   TAP State = DRCAPTURE
Device: TAP State = DRCAPTURE
DEBUG:  G   TAP State = DRSHIFT
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

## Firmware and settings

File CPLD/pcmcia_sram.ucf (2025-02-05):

# control signals from PCMCIA
NET "_CE1" LOC = "3";
NET "_CE2" LOC = "2";
NET "_REG" LOC = "32";
NET "_OE" LOC = "33";  # OE from PCMCIA
NET "_WE" LOC = "38";
NET "A0" LOC = "31"; # address bus bit 0
NET "A21" LOC = "37";
NET "D15" LOC = "34";

# switches/jumpers
NET "DISK_RAM" LOC = "22";
NET "RAM_SIZE" LOC = "23";

# control signals to memory
NET "CE_HIGH" LOC = "12";
NET "CE_LOW" LOC = "1";
NET "CE_SINGLE" LOC = "44";
NET "D15_A0" LOC = "36";
NET "_BYTE" LOC = "13";
#NET "oe_even" LOC = "33";
#NET "oe_oddlow" LOC = "29";
#NET "oe_odd" LOC = "28";
#NET "ce_attr_external" LOC = "25";

# address bus (in fact A1-A5)
NET "A<1>" LOC = "43";
NET "A<2>" LOC = "42";
NET "A<3>" LOC = "41";
NET "A<4>" LOC = "40";
NET "A<5>" LOC = "39";

# lowest 8 bits of data bus
NET "D<0>" LOC = "30";
NET "D<1>" LOC = "29";
NET "D<2>" LOC = "28";
NET "D<3>" LOC = "14";
NET "D<4>" LOC = "8";
NET "D<5>" LOC = "7";
NET "D<6>" LOC = "6";
NET "D<7>" LOC = "5";

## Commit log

2020-08-13 Respository init with v0.1 KiCAD files, Readme and License
    [PCMCIA_SRAM.kicad_pcb, PCMCIA_SRAM.sch]
2020-08-13 v1.0 KiCAD files, D15/A0 bypass by default
    [PCMCIA_SRAM.kicad_pcb, PCMCIA_SRAM.sch]
2021-01-18 Made pads shorter on PCMCIA connector. Corrected license to CC-BY-NC-SA.
    [PCMCIA_SRAM.kicad_pcb, PCMCIA_SRAM.sch]
2022-10-13 Kicad: conversion to Kicad 6 ; repo URL on PCB silkscreen.
    [PCMCIA_SRAM.kicad_pcb, PCMCIA_SRAM.kicad_sch, PCMCIA_SRAM.sch]
2022-10-13 Public repository init with schematic, Gerbers, ibom, CPLD xsvf, Photo, Readme, License
    [PCMCIA_SRAM-B_Cu.gbl, PCMCIA_SRAM-B_Mask.gbs, PCMCIA_SRAM-B_Paste.gbp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]
2024-05-09 Add photos of the assembly process

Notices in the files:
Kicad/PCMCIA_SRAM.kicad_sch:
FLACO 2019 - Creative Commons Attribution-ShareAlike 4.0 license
